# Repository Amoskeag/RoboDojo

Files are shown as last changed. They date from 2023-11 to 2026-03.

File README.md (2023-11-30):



# RoboDojo

This repo contains all the firmware and hardware for the RoboDojo.

If you're looking for the latest docs/builds, see our [Releases Page](https://github.com/Amoskeag/RoboDojo/releases).

# Getting Started

First, clone this repo (and optionally checkout a branch)

```shell
git clone --recurse-submodules https://github.com/Amoskeag/RoboDojo.git
cd RoboDojo
```

# Re-Init Submodules

Some libraries and resources are included as submodules, run the following
command to initialize them before opening the main sch

(If you get a missing library error, make sure to do this)

```shell
git submodule update --init --recursive
```

## Project Layout

If you want to use this project template for yourself, you can find it [here!](https://github.com/KenwoodFox/Project-Template)

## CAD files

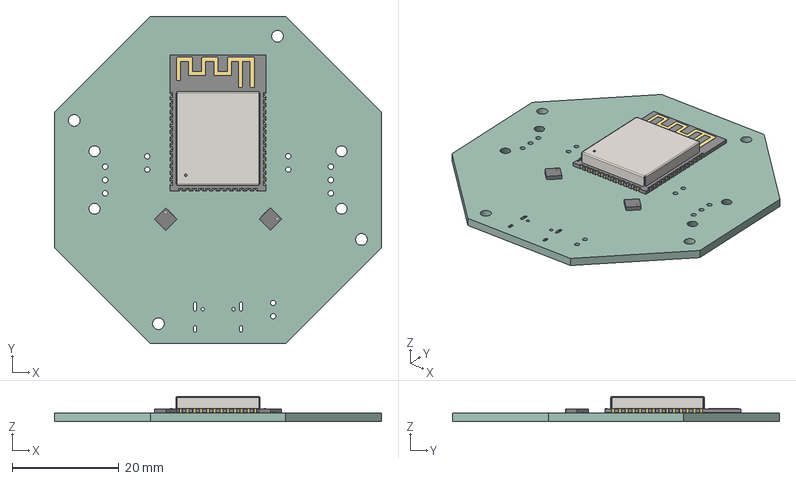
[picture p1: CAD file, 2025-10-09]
Hardware/ESP32 Robo Dev Board.step
61.3 x 61.3 x 4.75 mm
ESP32 Robo Dev Board PCB

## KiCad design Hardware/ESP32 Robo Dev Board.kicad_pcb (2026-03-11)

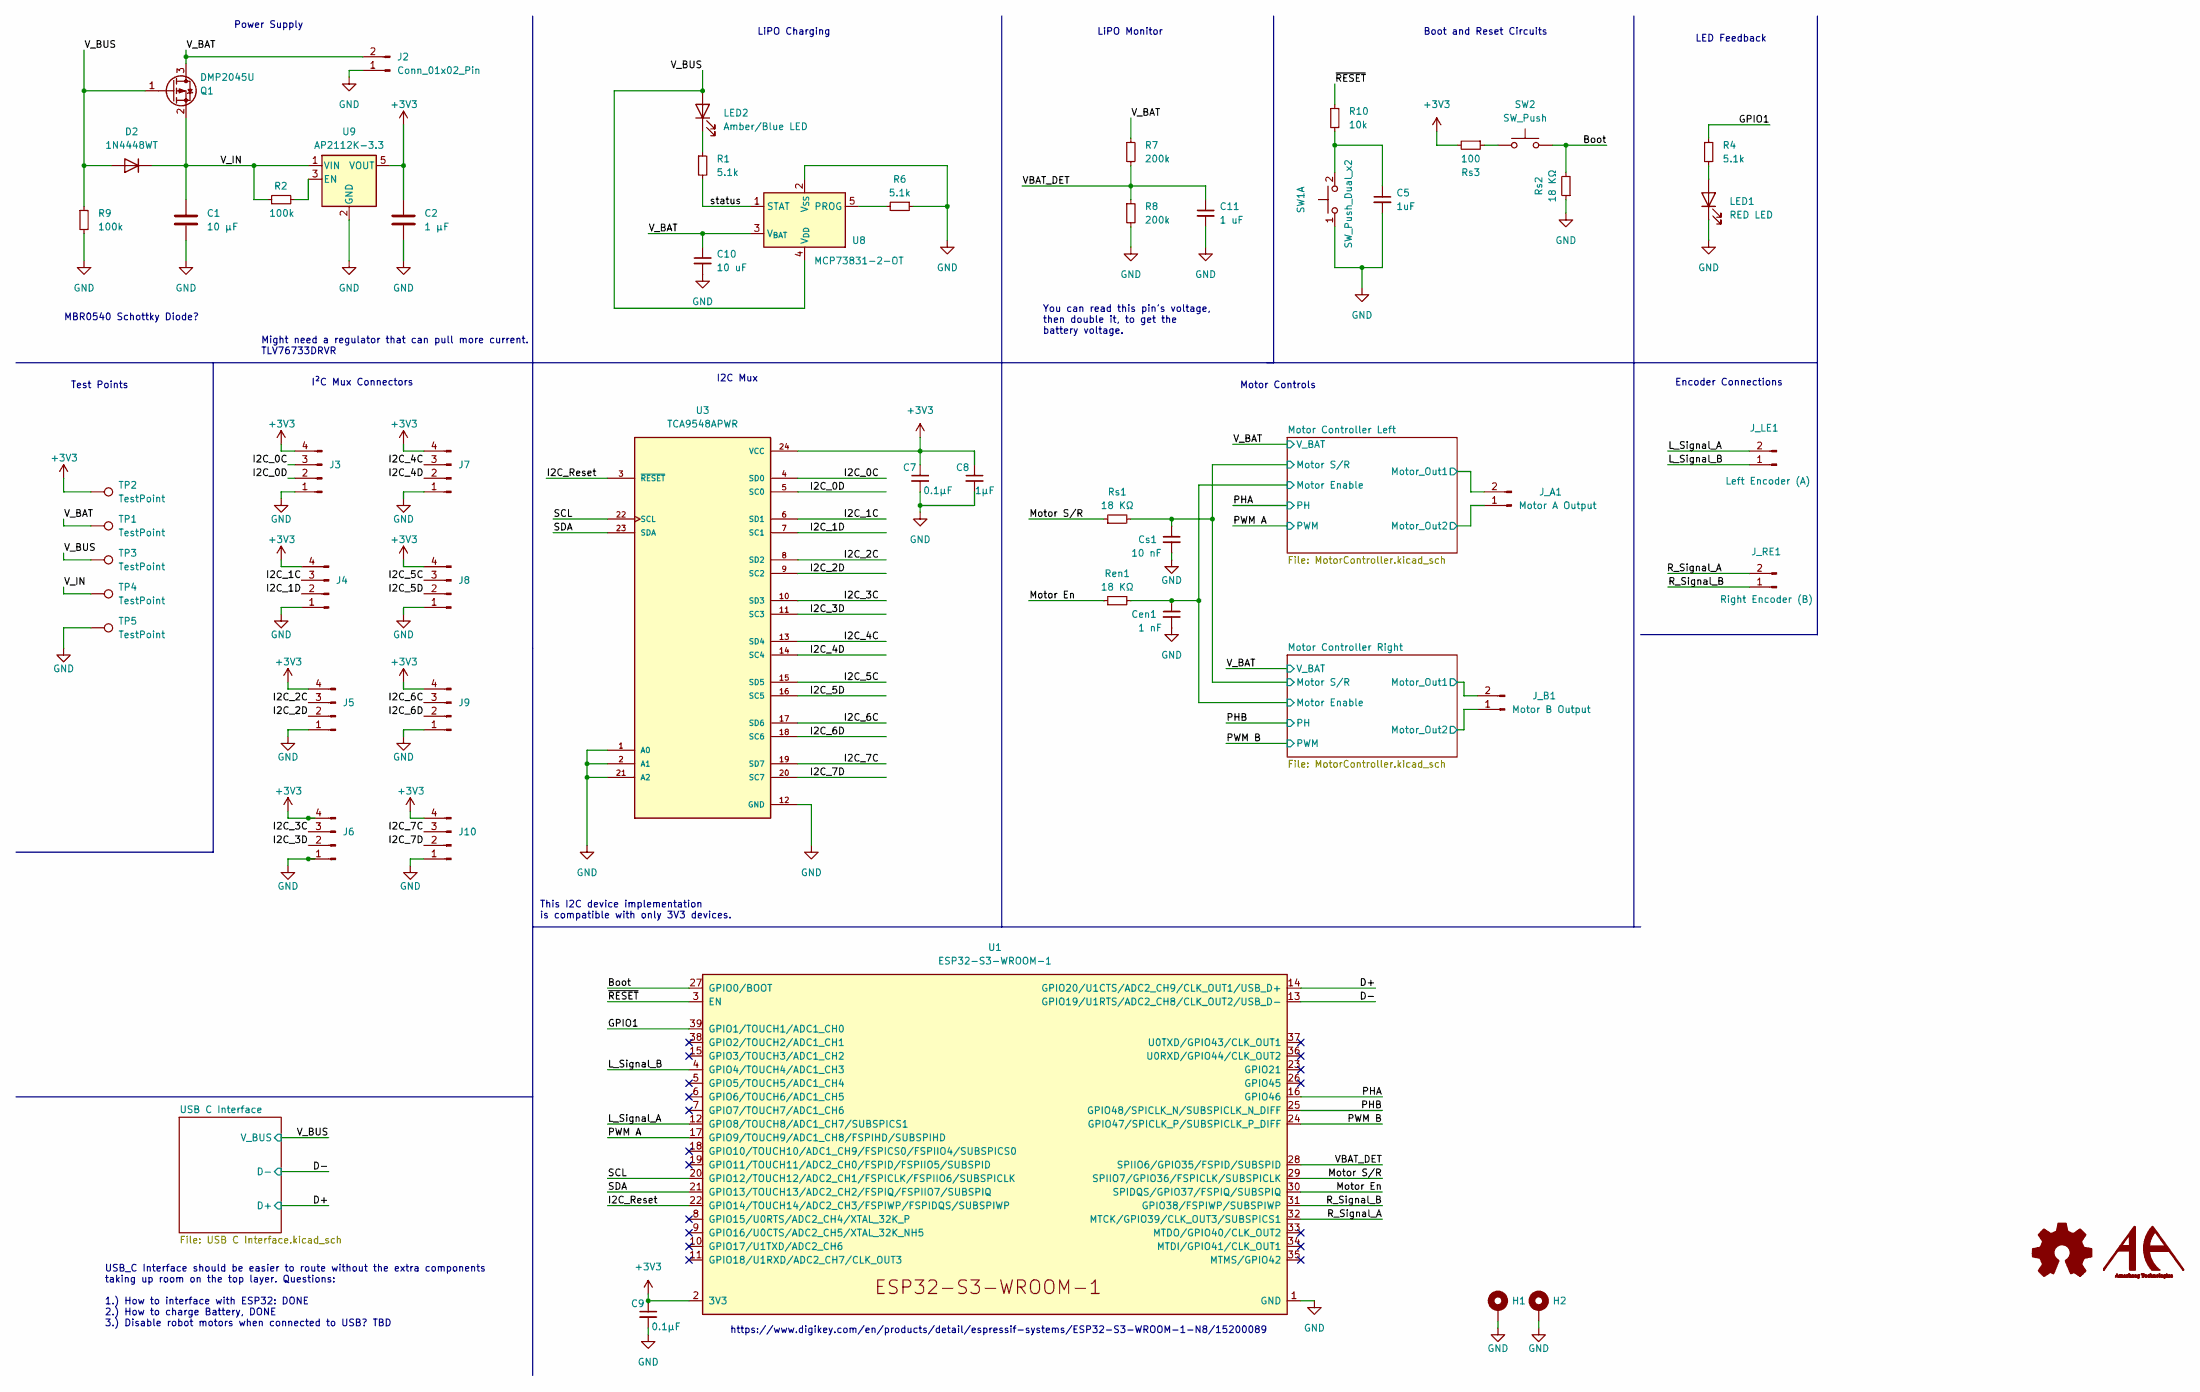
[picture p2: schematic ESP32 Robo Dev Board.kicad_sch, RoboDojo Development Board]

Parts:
C1: 10 µF; C_0805_2012Metric
C2: 1 µF; C_0805_2012Metric
C5: 1uF; C_0805_2012Metric
C7, C9: 0.1μF; C_0603_1608Metric
C8: 1μF; C_0603_1608Metric
C10: 10 uF; C_0805_2012Metric
C11: 1 uF; C_0805_2012Metric
Cen1: 1 nF; C_0603_1608Metric
Cs1: 10 nF; C_0603_1608Metric
D2: 1N4448WT; D_SOD-523
H1, H2: MountingHole_Pad; MountingHole_2.2mm_M2_DIN965_Pad
J2: Conn_01x02_Pin; JST_EH_B2B-EH-A_1x02_P2.50mm_Vertical
J3, J4, J5, J6, J7, J8, J9, J10: JST_SH_SM04B-SRSS-TB_1x04-1MP_P1.00mm_Horizontal
J_A1: Motor A Output; JST_EH_B2B-EH-A_1x02_P2.50mm_Vertical
J_B1: Motor B Output; JST_EH_B2B-EH-A_1x02_P2.50mm_Vertical
J_LE1: Left Encoder (A); JST_EH_B2B-EH-A_1x02_P2.50mm_Vertical
J_RE1: Right Encoder (B); JST_EH_B2B-EH-A_1x02_P2.50mm_Vertical
LED1: RED LED; LED_0805_2012Metric
LED2: Amber/Blue LED; LED_0805_2012Metric
Q1: DMP2045U; SOT-23
R1: 5.1k; R_0805_2012Metric
R2: 100k; R_0603_1608Metric
R4, R6: 5.1k; R_0603_1608Metric
R7, R8: 200k; R_0805_2012Metric
R9: 100k; R_0805_2012Metric
R10: 10k; R_0603_1608Metric
Ren1: 18 KΩ; R_0603_1608Metric
Rs1, Rs2: 18 KΩ; R_0603_1608Metric
Rs3: 100; R_0603_1608Metric
SW1: SW_Push_Dual_x2; SW_TH_Tactile_Omron_B3F-100x
SW2: SW_Push; SW_TH_Tactile_Omron_B3F-100x
TP1, TP2, TP3, TP4, TP5: TestPoint; TestPoint_Pad_D1.0mm
U1: ESP32-S3-WROOM-1
U3: TCA9548APWR; SOP65P640X120-24N; PARTREV G; DigiKey_Part_Number 296-34905-1-ND
U8: MCP73831-2-OT; SOT-23-5
U9: AP2112K-3.3; SOT-23-5

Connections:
+3V3: C2.1, C7.1, C8.1, C9.1, J3.4, J4.4, J5.4, J6.4, J7.4, J8.4, J9.4, J10.4, Rs3.2, TP2.1, U1.2 (3V3), U3.24 (VCC), U9.5 (VOUT)
/Boot: Rs2.2, SW2.2, U1.27 (GPIO0/BOOT)
/D+: U1.14 (GPIO20/U1CTS/ADC2_CH9/CLK_OUT1/USB_D+); also elsewhere on the board
/D-: U1.13 (GPIO19/U1RTS/ADC2_CH8/CLK_OUT2/USB_D-); also elsewhere on the board
/GPIO1: R4.1, U1.39 (GPIO1/TOUCH1/ADC1_CH0)
/I2C_0C: J3.3, U3.4 (SD0)
/I2C_0D: J3.2, U3.5 (SC0)
/I2C_1C: J4.3, U3.6 (SD1)
/I2C_1D: J4.2, U3.7 (SC1)
/I2C_2C: J5.3, U3.8 (SD2)
/I2C_2D: J5.2, U3.9 (SC2)
/I2C_3C: J6.3, U3.10 (SD3)
/I2C_3D: J6.2, U3.11 (SC3)
/I2C_4C: J7.3, U3.13 (SD4)
/I2C_4D: J7.2, U3.14 (SC4)
/I2C_5C: J8.3, U3.15 (SD5)
/I2C_5D: J8.2, U3.16 (SC5)
/I2C_6C: J9.3, U3.17 (SD6)
/I2C_6D: J9.2, U3.18 (SC6)
/I2C_7C: J10.3, U3.19 (SD7)
/I2C_7D: J10.2, U3.20 (SC7)
/I2C_Reset: U1.22 (GPIO14/TOUCH14/ADC2_CH3/FSPIWP/FSPIDQS/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), U3.3 (~RESET)
/L_Signal_A: J_LE1.2, U1.12 (GPIO8/TOUCH8/ADC1_CH7/SUBSPICS1)
/L_Signal_B: J_LE1.1, U1.4 (GPIO4/TOUCH4/ADC1_CH3)
/Motor Controller Left/EN/FAULT: Cen1.1, Ren1.2; also elsewhere on the board
/Motor Controller Left/Motor_Out1: J_A1.2; also elsewhere on the board
/Motor Controller Left/Motor_Out2: J_A1.1; also elsewhere on the board
/Motor Controller Left/STBY/RESET: Cs1.1, Rs1.2; also elsewhere on the board
/Motor Controller Right/Motor_Out1: J_B1.2; also elsewhere on the board
/Motor Controller Right/Motor_Out2: J_B1.1; also elsewhere on the board
/Motor En: Ren1.1, U1.30 (SPIDQS/GPIO37/FSPIQ/SUBSPIQ)
/Motor S/R: Rs1.1, U1.29 (SPIIO7/GPIO36/FSPICLK/SUBSPICLK)
/PHA: U1.16 (GPIO46); also elsewhere on the board
/PHB: U1.25 (GPIO48/SPICLK_N/SUBSPICLK_N_DIFF); also elsewhere on the board
/PWM A: U1.17 (GPIO9/TOUCH9/ADC1_CH8/FSPIHD/SUBSPIHD); also elsewhere on the board
/PWM B: U1.24 (GPIO47/SPICLK_P/SUBSPICLK_P_DIFF); also elsewhere on the board
/R_Signal_A: J_RE1.2, U1.32 (MTCK/GPIO39/CLK_OUT3/SUBSPICS1)
/R_Signal_B: J_RE1.1, U1.31 (GPIO38/FSPIWP/SUBSPIWP)
/SCL: U1.20 (GPIO12/TOUCH12/ADC2_CH1/FSPICLK/FSPIIO6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), U3.22 (SCL)
/SDA: U1.21 (GPIO13/TOUCH13/ADC2_CH2/FSPIQ/FSPIIO7/S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), U3.23 (SDA)
/VBAT_DET: C11.1, R7.2, R8.1, U1.28 (SPIIO6/GPIO35/FSPID/SUBSPID)
/V_BAT: C10.1, J2.2, Q1.3 (D), R7.1, TP1.1, U8.3 (V_{BAT}); also elsewhere on the board
/V_BUS: D2.2 (A), LED2.2 (A), Q1.1 (G), R9.1, TP3.1, U8.4 (V_{DD}); also elsewhere on the board
/V_IN: C1.1, D2.1 (K), Q1.2 (S), R2.1, TP4.1, U9.1 (VIN)
/status: R1.2, U8.1 (STAT)
/~RESET: R10.1, U1.3 (EN)
GND: C1.2, C2.2, C5.2, C7.2, C8.2, C9.2, C10.2, C11.2, Cen1.2, Cs1.2, H1.1, H2.1, J2.1, J3.1, J4.1, J5.1, J6.1, J7.1, J8.1, J9.1, J10.1, LED1.1 (K), R6.1, R8.2, R9.2, Rs2.1, SW1.1 (C), TP5.1, U1.1 (GND), U1.40 (GND), U1.41 (GND), U3.1 (A0), U3.2 (A1), U3.12 (GND), U3.21 (A2), U8.2 (V_{SS}), U9.2 (GND); also elsewhere on the board
unnamed: LED1.2 (A), R4.2
unnamed: LED2.1 (K), R1.1
unnamed: Rs3.1, SW2.1
unnamed: C5.1, R10.2, SW1.2 (D)
unnamed: R6.2, U8.5 (PROG)
unnamed: R2.2, U9.3 (EN)

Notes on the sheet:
USB_C Interface should be easier to route without the extra components taking up room on the top layer. Questions: 1.) How to interface with ESP32: DONE 2.) How to charge Battery, DONE 3.) Disable robot motors when connected to USB? TBD
LiPO Monitor
MBR0540 Schottky Diode?
https://www.digikey.com/en/products/detail/espressif-systems/ESP32-S3-WROOM-1-N8/15200089
Motor Controls
Encoder Connections
Boot and Reset Circuits
This I2C device implementation is compatible with only 3V3 devices.
You can read this pin's voltage, then double it, to get the battery voltage.
LED Feedback
I²C Mux Connectors
I2C Mux
Test Points
Power Supply
LiPO Charging
Might need a regulator that can pull more current. TLV76733DRVR

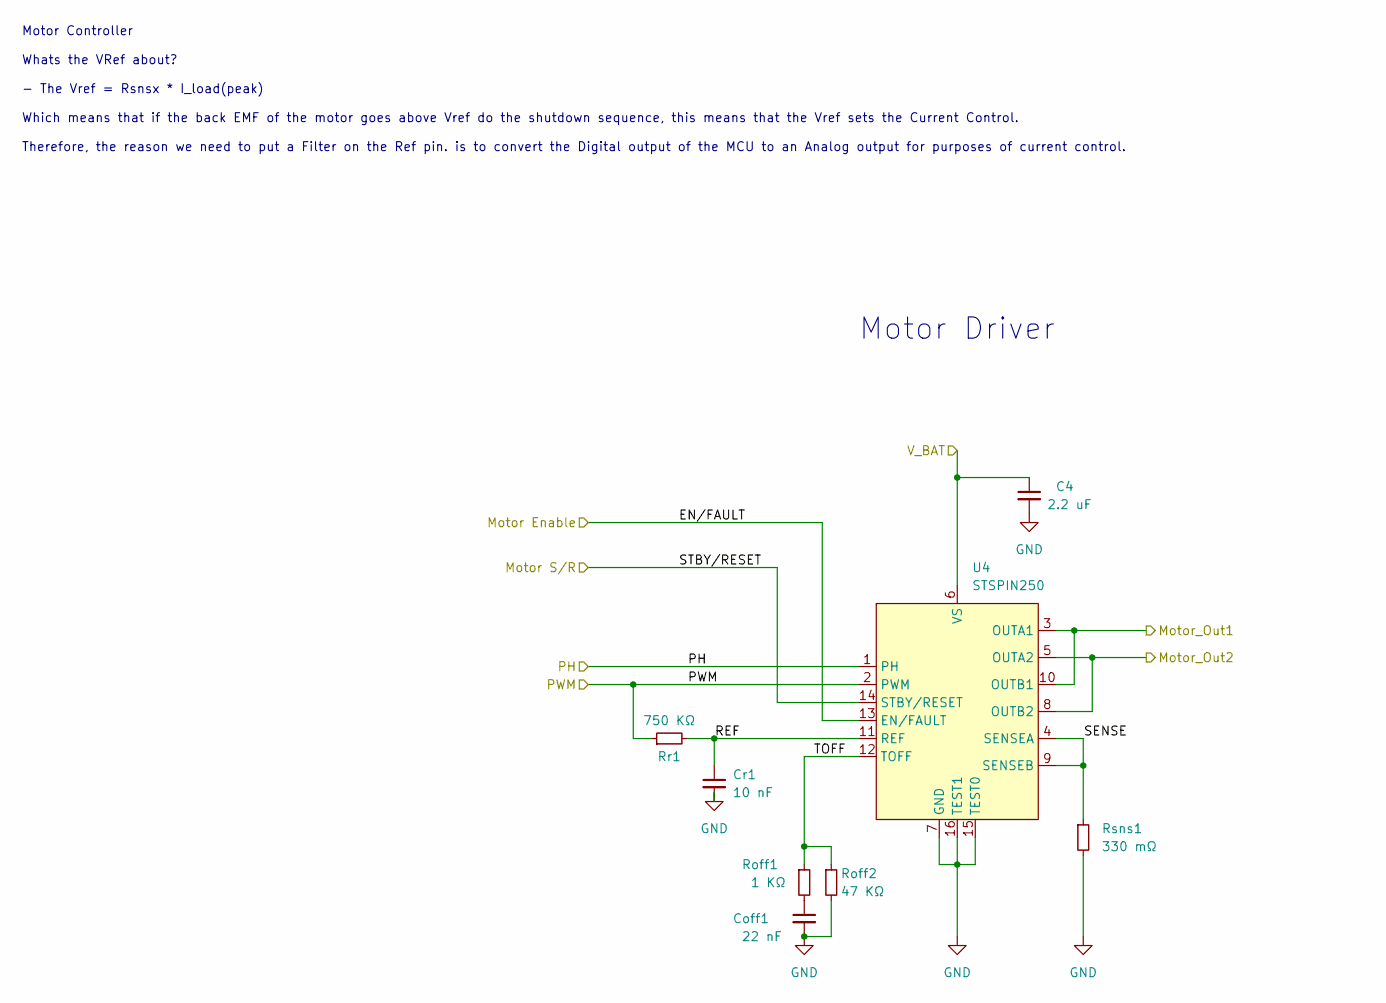
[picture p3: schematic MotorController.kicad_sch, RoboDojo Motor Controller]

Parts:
C4: 2.2 uF; C_0603_1608Metric
Coff1: 22 nF; C_0603_1608Metric
Cr1: 10 nF; C_0603_1608Metric
Roff1: 1 KΩ; R_0603_1608Metric
Roff2: 47 KΩ; R_0603_1608Metric
Rr1: 750 KΩ; R_0603_1608Metric
Rsns1: 330 mΩ; R_0805_2012Metric
U4: STSPIN250; ST_Microelectronics-STSPIN250-0

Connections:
/Motor Controller Left/EN/FAULT: U4.13 (EN/FAULT); also elsewhere on the board
/Motor Controller Left/Motor_Out1: U4.3 (OUTA1), U4.10 (OUTB1); also elsewhere on the board
/Motor Controller Left/Motor_Out2: U4.5 (OUTA2), U4.8 (OUTB2); also elsewhere on the board
/Motor Controller Left/REF: Cr1.1, Rr1.2, U4.11 (REF)
/Motor Controller Left/SENSE: Rsns1.1, U4.4 (SENSEA), U4.9 (SENSEB)
/Motor Controller Left/STBY/RESET: U4.14 (STBY/RESET); also elsewhere on the board
/Motor Controller Left/TOFF: Roff1.1, Roff2.1, U4.12 (TOFF)
/PHA: U4.1 (PH); also elsewhere on the board
/PWM A: Rr1.1, U4.2 (PWM); also elsewhere on the board
/V_BAT: C4.1, U4.6 (VS); also elsewhere on the board
GND: C4.2, Coff1.2, Cr1.2, Roff2.2, Rsns1.2, U4.7 (GND), U4.15 (TEST0), U4.16 (TEST1); also elsewhere on the board
unnamed: Coff1.1, Roff1.2

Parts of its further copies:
C6: 2.2 uF; C_0603_1608Metric
Coff2: 22 nF; C_0603_1608Metric
Cr2: 10 nF; C_0603_1608Metric
Roff3: 1 KΩ; R_0603_1608Metric
Roff4: 47 KΩ; R_0603_1608Metric
Rr2: 750 KΩ; R_0603_1608Metric
Rsns2: 330 mΩ; R_0805_2012Metric
U5: STSPIN250; ST_Microelectronics-STSPIN250-0

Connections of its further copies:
/Motor Controller Left/EN/FAULT: U5.13 (EN/FAULT); also elsewhere on the board
/Motor Controller Left/STBY/RESET: U5.14 (STBY/RESET); also elsewhere on the board
/Motor Controller Right/Motor_Out1: U5.3 (OUTA1), U5.10 (OUTB1); also elsewhere on the board
/Motor Controller Right/Motor_Out2: U5.5 (OUTA2), U5.8 (OUTB2); also elsewhere on the board
/Motor Controller Right/REF: Cr2.1, Rr2.2, U5.11 (REF)
/Motor Controller Right/SENSE: Rsns2.1, U5.4 (SENSEA), U5.9 (SENSEB)
/Motor Controller Right/TOFF: Roff3.1, Roff4.1, U5.12 (TOFF)
/PHB: U5.1 (PH); also elsewhere on the board
/PWM B: Rr2.1, U5.2 (PWM); also elsewhere on the board
/V_BAT: C6.1, U5.6 (VS); also elsewhere on the board
GND: C6.2, Coff2.2, Cr2.2, Roff4.2, Rsns2.2, U5.7 (GND), U5.15 (TEST0), U5.16 (TEST1); also elsewhere on the board
unnamed: Coff2.1, Roff3.2

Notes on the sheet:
Motor Driver
Motor Controller Whats the VRef about? - The Vref = Rsnsx * I_load(peak) Which means that if the back EMF of the motor goes above Vref do the shutdown sequence, this means that the Vref sets the Current Control. Therefore, the reason we need to put a Filter on the Ref pin. is to convert the Digital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

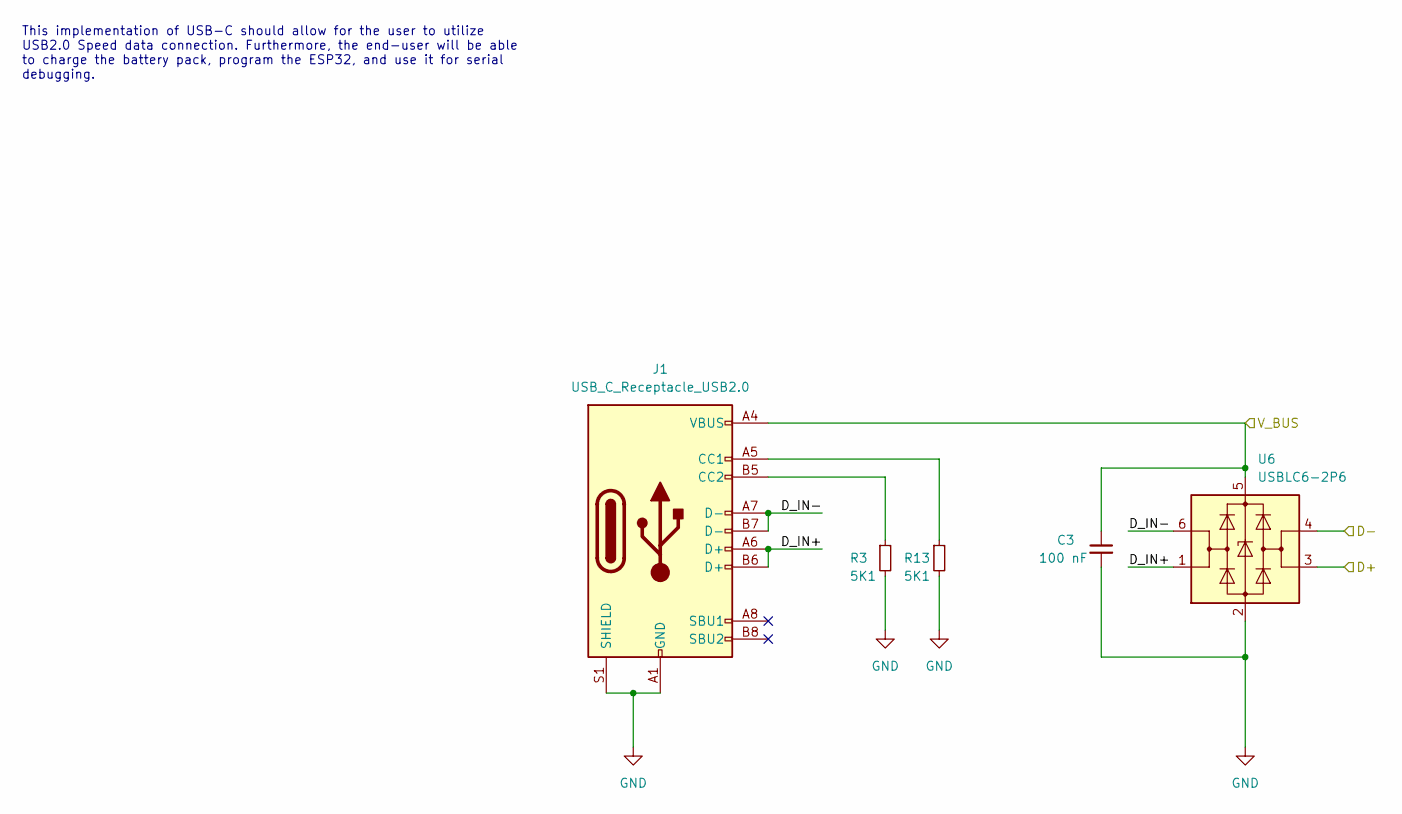
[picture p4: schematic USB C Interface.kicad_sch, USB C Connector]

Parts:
C3: 100 nF; C_0603_1608Metric
J1: USB_C_Receptacle_USB2.0; GCT_USB4110GFA
R3, R13: 5K1; R_0603_1608Metric
U6: USBLC6-2P6; SOT-666

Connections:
/D+: U6.3 (I/O2); also elsewhere on the board
/D-: U6.4 (I/O2); also elsewhere on the board
/USB C Interface/D_IN+: J1.A6 (D+), J1.B6 (D+), U6.1 (I/O1)
/USB C Interface/D_IN-: J1.A7 (D-), J1.B7 (D-), U6.6 (I/O1)
/V_BUS: C3.1, J1.A4 (VBUS), J1.A9 (VBUS), J1.B4 (VBUS), J1.B9 (VBUS), U6.5 (VBUS); also elsewhere on the board
GND: C3.2, J1.A1 (GND), J1.A12 (GND), J1.B1 (GND), J1.B12 (GND), J1.S1 (SHIELD), R3.2, R13.2, U6.2 (GND); also elsewhere on the board
unnamed: J1.A5 (CC1), R13.1
unnamed: J1.B5 (CC2), R3.1

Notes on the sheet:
This implementation of USB-C should allow for the user to utilize USB2.0 Speed data connection. Furthermore, the end-user will be able to charge the battery pack, program the ESP32, and use it for serial debugging.

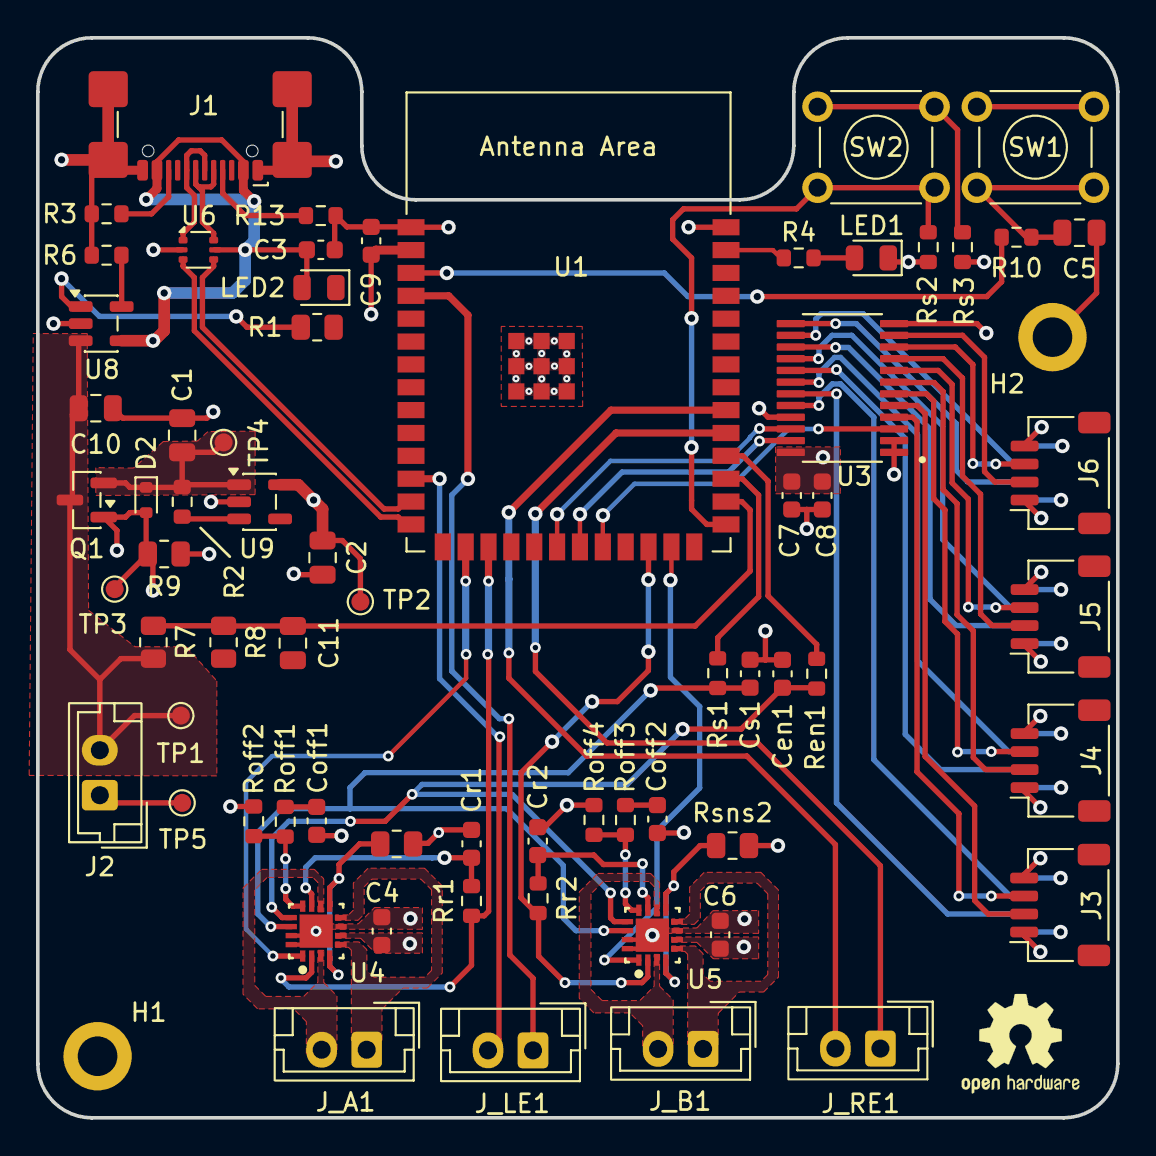
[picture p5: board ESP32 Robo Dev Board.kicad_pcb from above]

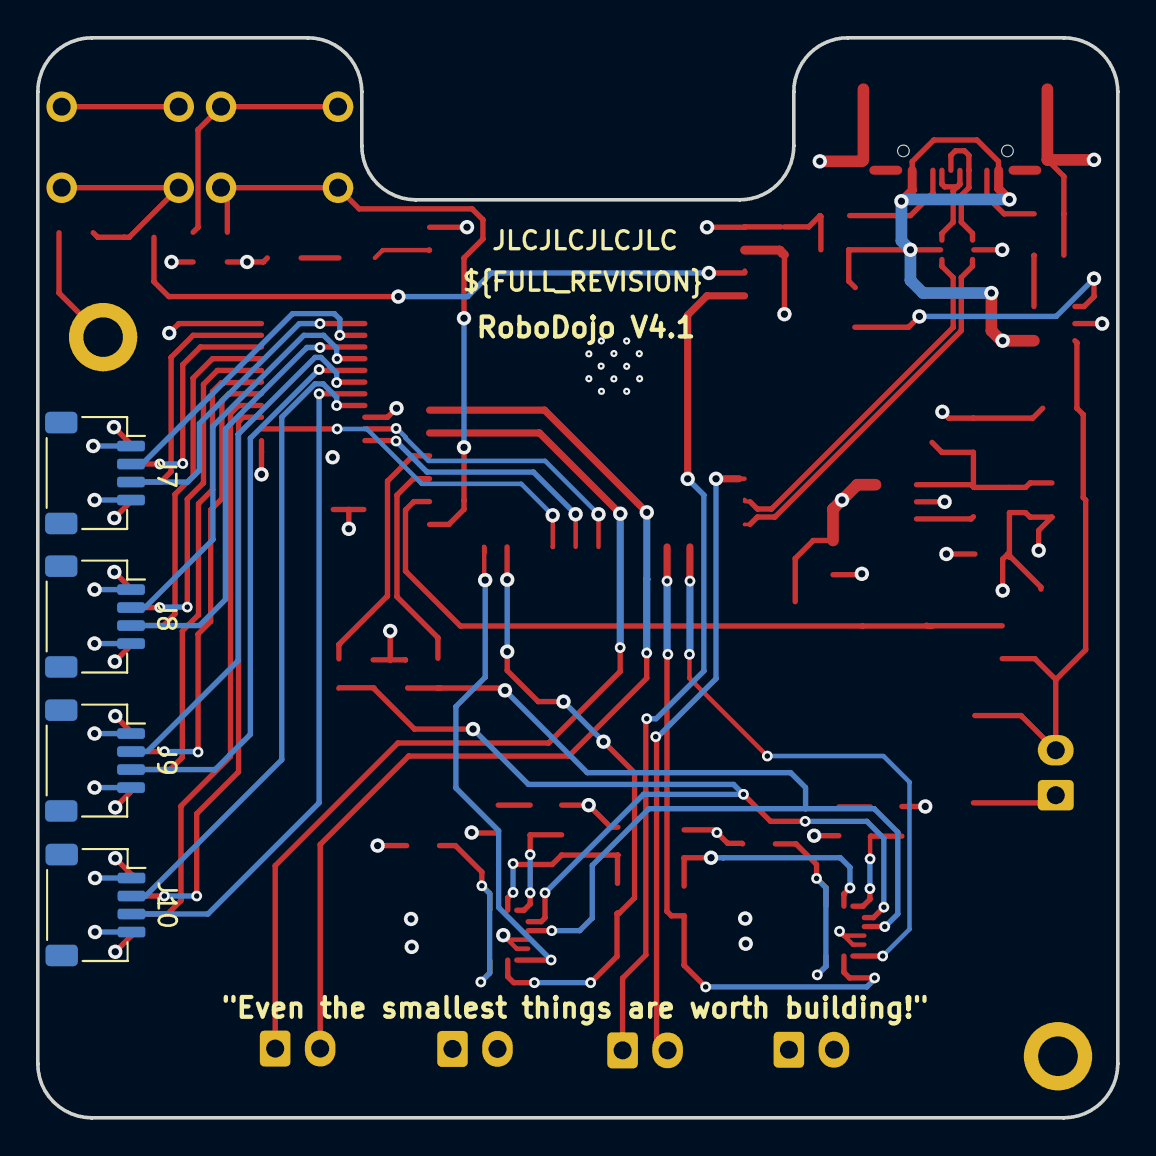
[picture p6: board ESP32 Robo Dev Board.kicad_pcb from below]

Board: 4 copper layers, 60.0 x 60.0 mm, 73 parts (4 on the bottom side), 65 nets.

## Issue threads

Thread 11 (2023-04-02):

Mount Incorrect

Amoskeag, 2023-04-02:
The Motors being used cannot fit with the current hole placement. The holes need to be rotated 90 degrees, or else you cant get access to the connector for encoders and motor power!

Closed 2023-04-05.

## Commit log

2022-12-01 First Finished Version 0.1.
    [ESP32 Robo Dev Board.kicad_pcb, ESP32 Robo Dev Board.kicad_sch, MotorController.kicad_sch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]
2022-12-01 Add battery connector
    [ESP32 Robo Dev Board.kicad_pcb, ESP32 Robo Dev Board.kicad_sch, MotorController.kicad_sch]
2022-12-01 Use robots
    [ESP32 Robo Dev Board.kicad_pcb, ESP32 Robo Dev Board.kicad_sch, MotorController.kicad_sch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]
2022-12-01 More robots (and cleanups)
    [ESP32 Robo Dev Board.kicad_pcb]
2022-12-01 Fixup! Better anotations
    [ESP32 Robo Dev Board.kicad_pcb, ESP32 Robo Dev Board.kicad_sch]
2022-12-02 Fix Range Finder Locations
    [ESP32 Robo Dev Board.kicad_pcb]
2022-12-04 Rebuild Layout
    Took the V1.0 Layout and reworked it.
    [ESP32 Robo Dev Board.kicad_pcb, ESP32 Robo Dev Board.kicad_sch]
2022-12-05 Update ESP32 Robo Dev Board.kicad_pcb
    Update Silkscreen, Move Components to better fit silkscreen
    [ESP32 Robo Dev Board.kicad_pcb]
2022-12-10 Add I2C IC
    Added TCA9548A mux interface
    [ESP32 Robo Dev Board.kicad_pcb]
2022-12-10 Update ESP32 Robo Dev Board.kicad_sch
    [ESP32 Robo Dev Board.kicad_sch]
2023-01-27 Update ESP32 Robo Dev Board.kicad_pcb
    Add in TCA9548A Multiplexer.
    Reroute traces.
    Prepare for Proximity Sensor overhaul
    [ESP32 Robo Dev Board.kicad_pcb]
2023-01-29 Add new array for sensors
    Add in sensor array
    Begin trace reroute
    [ESP32 Robo Dev Board.kicad_pcb, ESP32 Robo Dev Board.kicad_sch, Range Finder Array.kicad_sch]
2023-01-29 Fix 3d and placement
    [ESP32 Robo Dev Board.kicad_pcb]
2023-01-29 I2C Interface Established
    Run Traces for all Sensors
    Mark unused Pins
    Sub-Optimally run said traces
    [ESP32 Robo Dev Board.kicad_pcb, ESP32 Robo Dev Board.kicad_sch, Range Finder Array.kicad_sch]
2023-01-30 Fix DRC errors
    Fix DRC errors, move sensor array closer to center
    [ESP32 Robo Dev Board.kicad_pcb]
2023-01-30 Upkeep
    Add GND to mounts
    Move traces from antenna
    [ESP32 Robo Dev Board.kicad_pcb]
2023-01-30 Fix Thoughholes
    Fixed Schematic Parity DRC issue.
    Taught some standard practices by the Foxy Boy
    [ESP32 Robo Dev Board.kicad_pcb, ESP32 Robo Dev Board.kicad_sch, MotorController.kicad_sch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]
2023-01-30 Add Throughholes
    Added Through holes in a far better what than before.
    Got advice from the Foxy Fellow
    [ESP32 Robo Dev Board.kicad_sch, MotorController.kicad_sch, Range Finder Array.kicad_sch]
2023-03-28 Fix Traces
    trace fixes
    [ESP32 Robo Dev Board.kicad_pcb, ESP32 Robo Dev Board.kicad_sch, MotorController.kicad_sch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]
2023-03-28 Attempt to recover pcb
    [ESP32 Robo Dev Board.kicad_pcb]
2023-04-06 Update, Fix DRC Errors after The Great Recovery
    Traces got messed up, fixed and tried to establish a keep out zone for the Antena.
    [ESP32 Robo Dev Board.kicad_pcb]
2023-08-18 Fixed Traces
    Fix Traces that I messed up when I left college. Getting back to the project.
    [ESP32 Robo Dev Board.kicad_pcb, ESP32 Robo Dev Board.kicad_sch]
2023-08-18 Add USB C in Schematic
    Added USB C support in sch not on PCB yet
    [ESP32 Robo Dev Board.kicad_sch, USB C Interface.kicad_sch]
2023-09-06 Add VL53L0X
    Added VL53L0X range finders and reworked traces.
    [ESP32 Robo Dev Board.kicad_pcb, ESP32 Robo Dev Board.kicad_sch, Range Finder Array.kicad_sch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]
2023-11-28 Fix Reroute
    Traces are getting messy, Moved the TOF sensors to be 3mm from edge of board. USB-C getting moved possibly. Changed Resistor and Capacitor footprints to better fit board space requirements.
    [ESP32 Robo Dev Board.kicad_pcb, ESP32 Robo Dev Board.kicad_sch, MotorController.kicad_sch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]
2023-11-28 Update, all passive components.
    Placed all parts, time to route.
    [ESP32 Robo Dev Board.kicad_pcb]
2023-11-29 Update Trace Routing
    Lots of DRC errors related to mismatching Library entries. Thermal Relief Parameters need to be checked. USB-C Remains a swept under the rug feature.
    [ESP32 Robo Dev Board.kicad_pcb]
2023-11-29 Update ESP32 Robo Dev Board.kicad_pcb
    [ESP32 Robo Dev Board.kicad_pcb]
2023-11-30 add kicad7 footprint fp lib table
    [ESP32 Robo Dev Board.kicad_pcb]
2023-11-30 Remove USB-C
    USB C needs 4 layer for this. Remove now, profit later.
    [ESP32 Robo Dev Board.kicad_pcb, ESP32 Robo Dev Board.kicad_sch]
2023-11-30 Removed USB C
    rerouted traces
    [ESP32 Robo Dev Board.kicad_pcb]
2023-11-30 Move Traces for Cleanup
    Cleanup for Version 3 Release
    [ESP32 Robo Dev Board.kicad_pcb]
2023-12-06 Small update, traces
    Increase spacing between traces on left side
    [ESP32 Robo Dev Board.kicad_pcb]
2025-10-09 Squashed commit of the following:
    commit e6d18f1838a18780ff985c290e2821e2ac438ddc
    Author: KenwoodFox <kenwood364@gmail.com>
    Date: Sun Oct 5 18:23:23 2025 -0400
    Tweaked n' fixed things with @Amoskeag
    commit 133f082a76a13551d058af83ac953c852f82cbfb
    Author: Arthur Aznive <61330561+Amoskeag@users.noreply.github.com>
    Date: Sun Oct 5 10:51:39 2025 -0400
    Update I2C Bus Connections
    Channel 4 of I2C was not connected, will make traces pretty later.
    commit 1fc084a3994e8cc2965589d6eb11268a7396225d
    Author: Arthur Aznive <61330561+Amoskeag@users.noreply.github.com>
    Date: Sun Oct 5 10:36:15 2025 -0400
    Board Refactor, Updated Parts
    Updated Board layout and added new parts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
    [ESP32 Robo Dev Board.kicad_pcb, ESP32 Robo Dev Board.kicad_sch, ESP32 Robo Dev Board.step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]
2025-10-12 Fix Footprint Targets
    Fixed DRC errors on footprints.
    [ESP32 Robo Dev Board.kicad_pcb]
2025-10-13 Add JST Connectors for Encoders
    Added JST Connectors for my Encoders to attach to.
    Fixed all DRC Errors.
    [ESP32 Robo Dev Board.kicad_pcb, ESP32 Robo Dev Board.kicad_sch]
2025-10-16 Increase Trace Widths
    Increased the smallest trace width from 0.25 mm to 0.3 mm and beefed up all the other traces.
    [ESP32 Robo Dev Board.kicad_pcb]
2025-10-19 Clean Up Schematic
    Fixed Schematic notes, and formatting
    [ESP32 Robo Dev Board.kicad_pcb, ESP32 Robo Dev Board.kicad_sch, MotorController.kicad_sch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]
2025-10-19 Fix Bad 3D Model Path
    USB-C Connector Model was not being rendered, fixed path issue.
    [ESP32 Robo Dev Board.kicad_pcb]
2026-02-16 Fix DRC Errors
    Silkscreen overlapping and some trace width modification.
    [ESP32 Robo Dev Board.kicad_pcb, ESP32 Robo Dev Board.kicad_sch]
2026-02-16 Update Layer Names
    Looks like changing layer names makes JLC not recognize layers, changed back to default settings for naming.
    [ESP32 Robo Dev Board.kicad_pcb]
2026-03-11 Standardize I²C Bus and Route USB-C
    Taking the opportunity to reroute and place STEMMA QT (JST-SH) Connectors to standardize the use of the I²C Multiplexer. Also took the chance to clean up the USB-C power supply and data line routing.
    [ESP32 Robo Dev Board.kicad_pcb, ESP32 Robo Dev Board.kicad_sch, MotorController.kicad_sch]
2026-03-11 Fix DRC Errors
    Fixed small DRC errors.
    [ESP32 Robo Dev Board.kicad_pcb]
